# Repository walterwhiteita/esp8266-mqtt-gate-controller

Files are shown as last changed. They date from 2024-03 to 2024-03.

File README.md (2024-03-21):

# MQTT-ESPGate: Retrofit Solution for Gate Control Boards

Welcome to the ESPGate repository! This project offers a comprehensive retrofit solution tailored to upgrade a variety of gate control boards. Leveraging the power of MQTT and ESP8266 modules, this solution provides seamless control over gate automation systems. The repository hosts the design files and documentation for a specialized PCB crafted specifically for this purpose, ensuring easy integration and enhanced functionality for existing gate control setups.

## Project Description

The project aims to upgrade existing automatic gates by adding advanced control and monitoring features. The provided PCB is designed to be integrated into the control boards of installed gates, providing a standardized interface for adding new functionalities without the need to replace the entire system.

## Key Features

- **Remote Commands**: The PCB allows sending remote commands to the gate, enabling opening, closing, and other programmable actions.
- **Status Monitoring**: It's possible to read the current status of the gate, including open, closed signals, and error states.
- **Addition of Clean Contact**: The option to add a clean contact is provided, allowing integration with external control systems or safety devices.

## Repository Structure

- `design/`: Contains PCB design files, including schematics and layouts.
- `docs/`: Additional project documentation.
- `examples/`: Code examples for interfacing with the PCB.
- `LICENSE`: Project license.
- `README.md`: This documentation file.

## Hardware and Software Requirements

### Hardware

- **Opening and Closing Contacts**: The opening and closing contacts present on the gate control board are essential for sending opening and closing commands through our PCB.
- **Indicator Light (optional)**: If available, the indicator light provides visual feedback on the gate's status. In cases where the indicator light is not available, the clean contact already present on our PCB can be used to connect a sensor that detects the gate's open or closed status.

### Software

- **WiFi Connection**: A WiFi connection is required to facilitate communication between the PCB and the MQTT broker, as well as for any configuration operations via mobile devices or computers.
- **MQTT Broker**: An MQTT broker must be available and running, acting as an intermediary for communication between the PCB and other devices or services.

These hardware and software requirements are essential to ensure the proper and reliable operation of the gate control system through the PCB.

## Contributions

Contributions to this project are welcome. Please follow the contribution guidelines described in the `CONTRIBUTING.md` file.

## License

This project is licensed under the [GNU General Public License v3.0](LICENSE). Please refer to the license file for further information.

## Contact

For questions, bug reports, or other inquiries, please contact [Repository Owner's Name](mailto:dimieri00@gmail.com).

---
© 2024 [Repository Owner's Name](https://github.com/walterwhiteita)

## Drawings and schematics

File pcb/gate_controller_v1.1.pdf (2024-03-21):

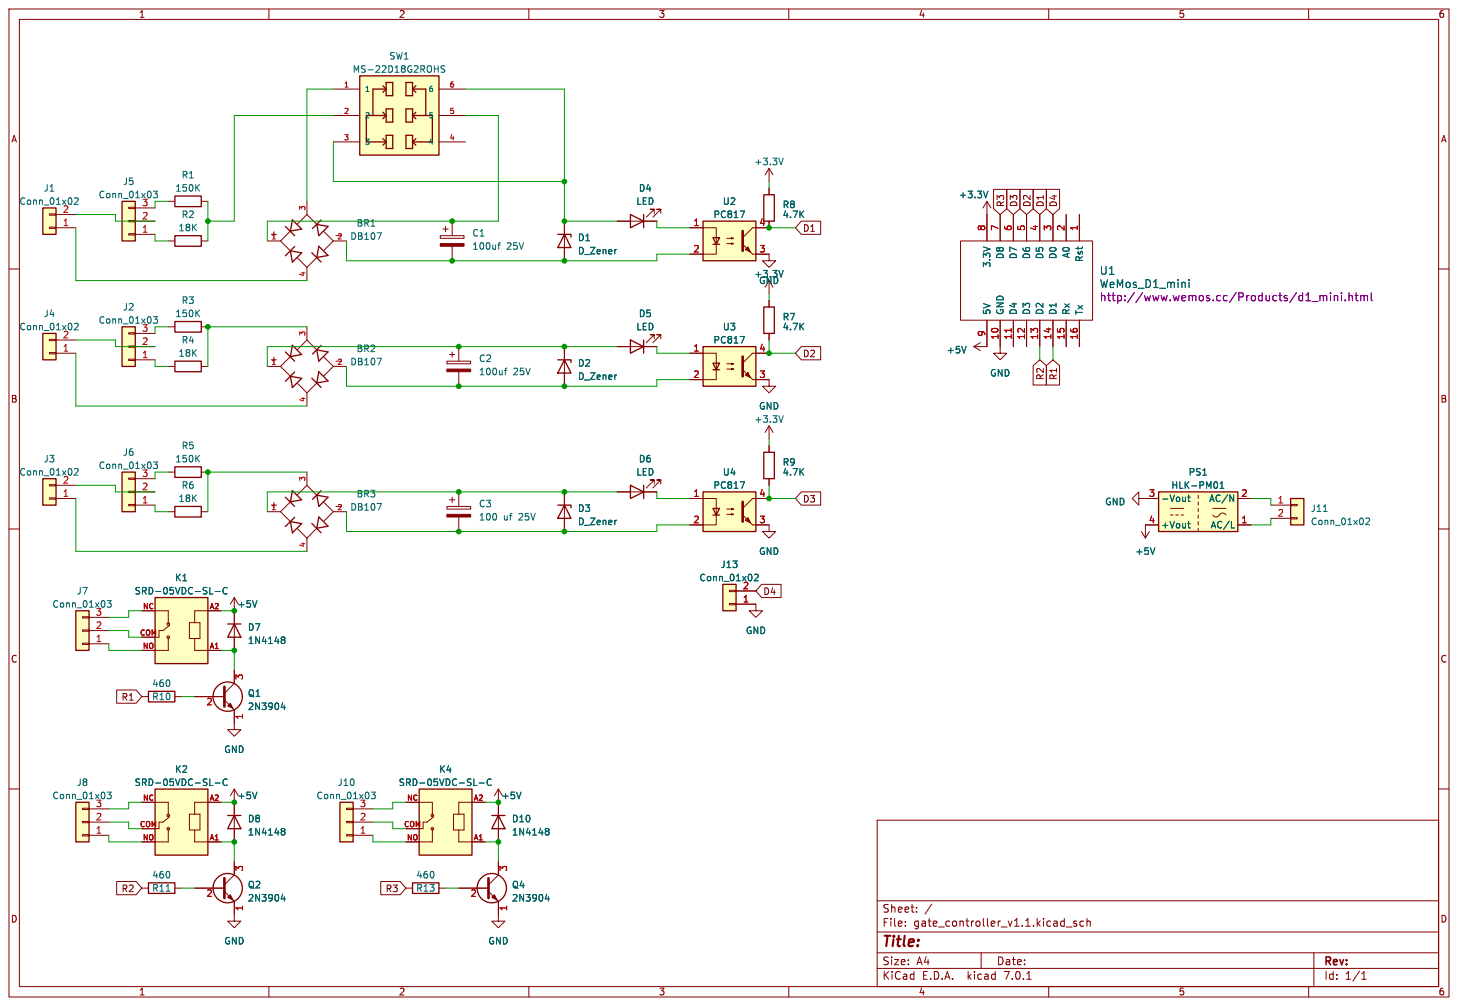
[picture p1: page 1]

http://www.wemos.cc/Products/d1_mini.html D6

Id: 1/1 Title: File: gate_controller_v1.1.kicad_sch Sheet: /

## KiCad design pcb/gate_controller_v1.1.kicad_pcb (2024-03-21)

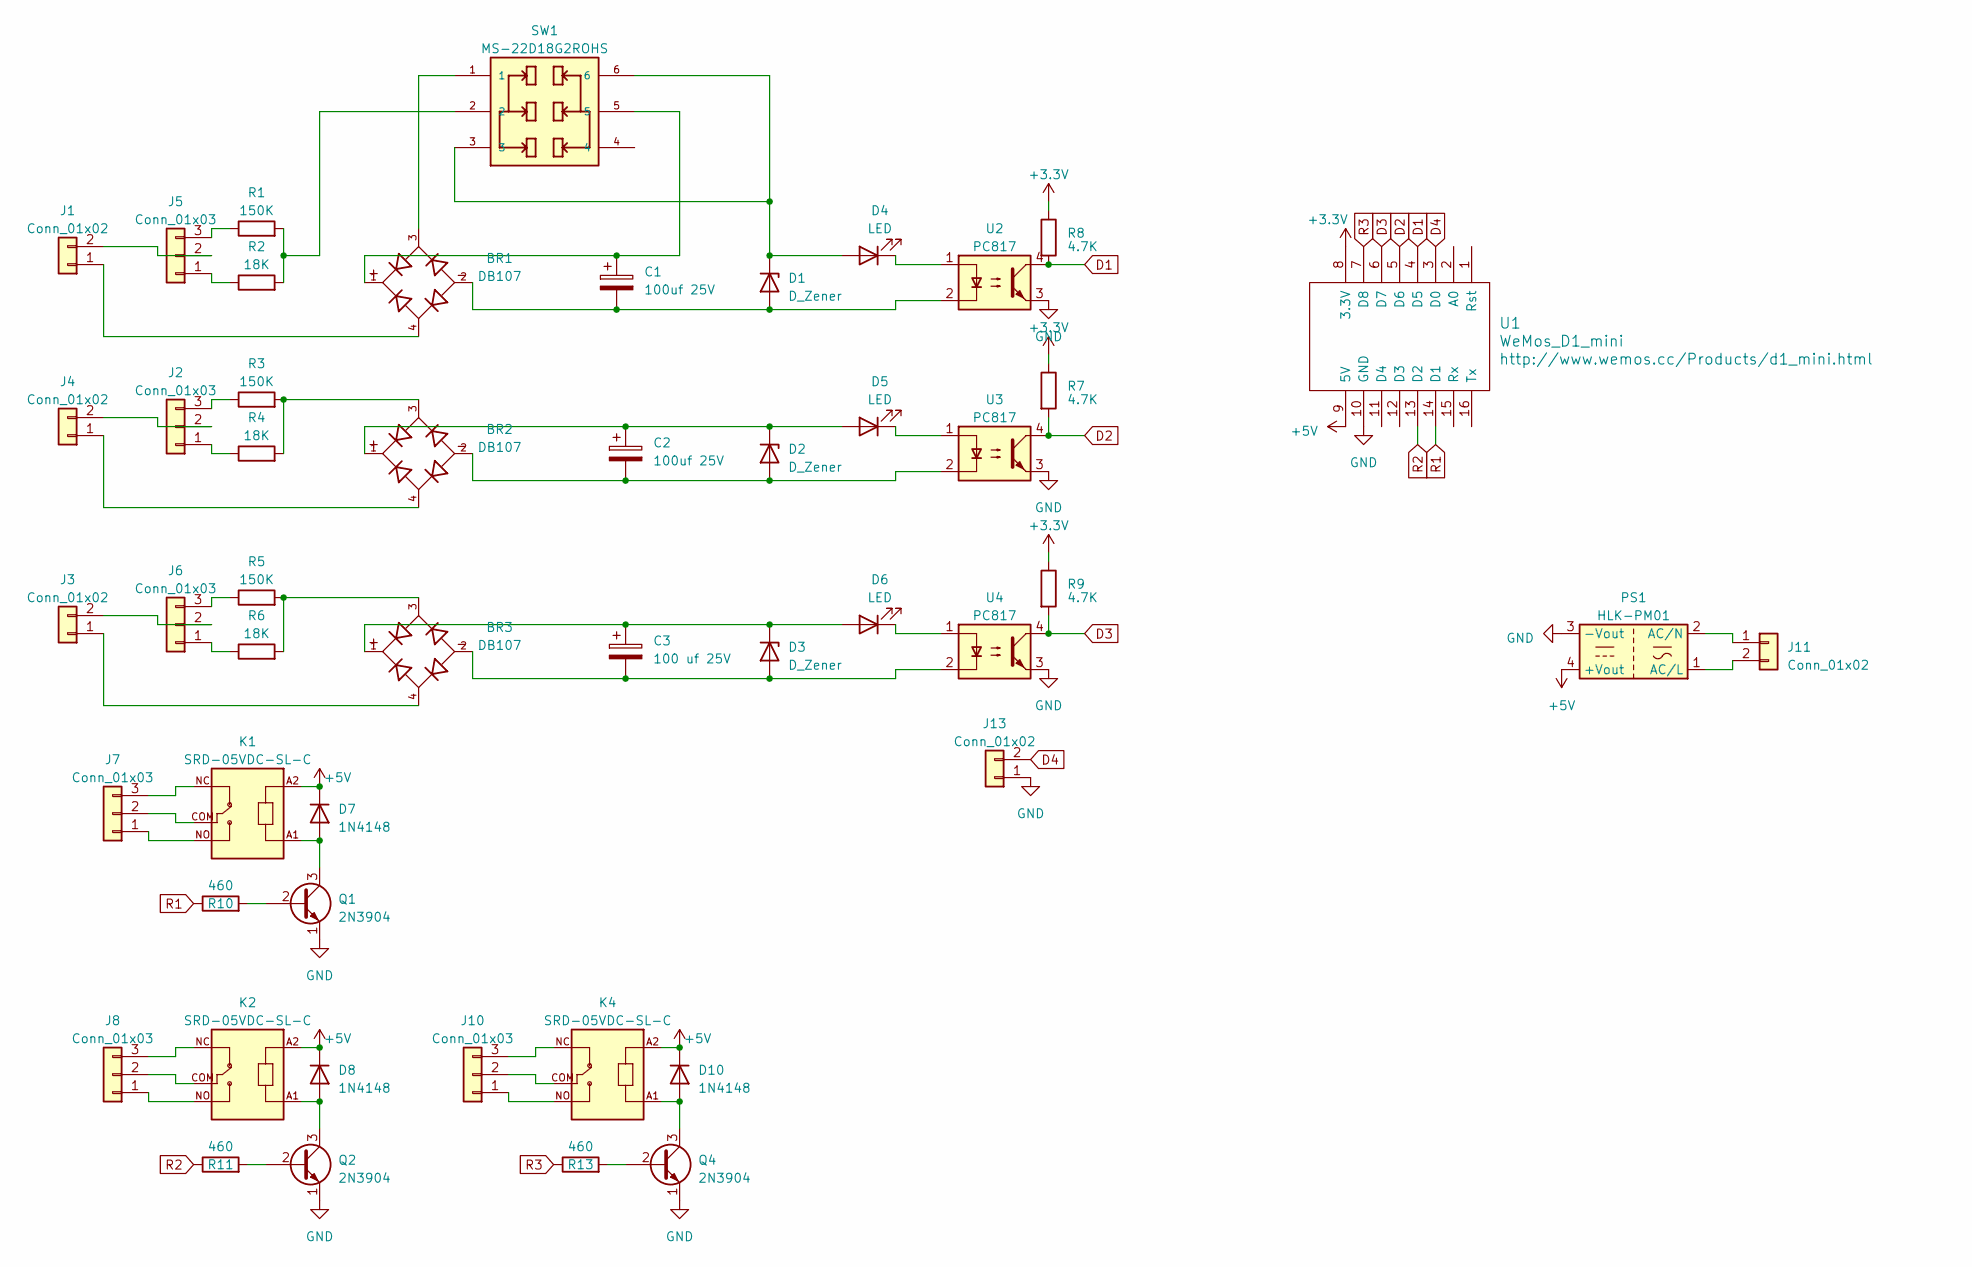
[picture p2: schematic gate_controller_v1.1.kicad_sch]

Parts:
BR1, BR2, BR3: DB107; DIP825W50P509L880H320Q4; PARTREV 13
C1, C2: 100uf 25V; CP_Radial_D6.3mm_P2.50mm
C3: 100 uf 25V; CP_Radial_D6.3mm_P2.50mm
D1, D2, D3: D_Zener; D_DO-41_SOD81_P2.54mm_Vertical_AnodeUp
D4, D5, D6: LED; LED_D5.0mm
D7, D8, D10: 1N4148; D_DO-35_SOD27_P7.62mm_Horizontal
J1, J3, J4, J11: Conn_01x02; TerminalBlock_bornier-2_P5.08mm
J2, J5, J6: Conn_01x03; PinHeader_1x03_P2.54mm_Vertical
J7, J8, J10: Conn_01x03; TerminalBlock_bornier-3_P5.08mm
J13: Conn_01x02; PhoenixContact_MCV_1,5_2-G-3.81_1x02_P3.81mm_Vertical
K1, K2, K4: SRD-05VDC-SL-C; RELAY_SRD-05VDC-SL-C
PS1: HLK-PM01; Converter_ACDC_HiLink_HLK-PMxx
Q1, Q2, Q4: 2N3904; TO-92_Inline
R1, R3, R5: 150K; R_Axial_DIN0414_L11.9mm_D4.5mm_P20.32mm_Horizontal
R2, R4, R6: 18K; R_Axial_DIN0414_L11.9mm_D4.5mm_P20.32mm_Horizontal
R7, R8, R9: 4.7K; R_Axial_DIN0207_L6.3mm_D2.5mm_P2.54mm_Vertical
R10, R11, R13: 460; R_Axial_DIN0207_L6.3mm_D2.5mm_P2.54mm_Vertical
SW1: MS-22D18G2ROHS; SW_MS-22D18G2ROHS
U1: WeMos_D1_mini; wemos-d1-mini-connectors-only
U2, U3, U4: PC817; DIP-4_W7.62mm

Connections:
+3.3V: R7.1, R8.1, R9.1, U1.8 (3.3V)
+5V: D7.1 (K), D8.1 (K), D10.1 (K), K1.A2, K2.A2, K4.A2, PS1.4 (+Vout), U1.9 (5V)
D1: R8.2, U1.4 (D5), U2.4
D2: R7.2, U1.5 (D6), U3.4
D3: R9.2, U1.6 (D7), U4.4
D4: J13.2, U1.3 (D0)
GND: J13.1, PS1.3 (-Vout), Q1.1 (E), Q2.1 (E), Q4.1 (E), U1.10 (GND), U2.3, U3.3, U4.3
unnamed: BR1.1, C1.1, SW1.5
unnamed: BR1.3, SW1.1
unnamed: BR2.3, R3.2, R4.2
unnamed: BR3.3, R5.2, R6.2
unnamed: BR1.2, C1.2, D1.2 (A), U2.2
unnamed: D1.1 (K), D4.2 (A), SW1.3, SW1.6
unnamed: BR2.2, C2.2, D2.2 (A), U3.2
unnamed: BR2.1, C2.1, D2.1 (K), D5.2 (A)
unnamed: BR3.2, C3.2, D3.2 (A), U4.2
unnamed: BR3.1, C3.1, D3.1 (K), D6.2 (A)
unnamed: D4.1 (K), U2.1
unnamed: D5.1 (K), U3.1
unnamed: D6.1 (K), U4.1
unnamed: D7.2 (A), K1.A1, Q1.3 (C)
unnamed: D8.2 (A), K2.A1, Q2.3 (C)
unnamed: D10.2 (A), K4.A1, Q4.3 (C)
unnamed: BR1.4, J1.1
unnamed: J1.2, J5.2
unnamed: J2.1, R4.1
unnamed: J2.2, J4.2
unnamed: J2.3, R3.1
unnamed: BR3.4, J3.1
unnamed: J3.2, J6.2
unnamed: BR2.4, J4.1
unnamed: J5.1, R2.1
unnamed: J5.3, R1.1
unnamed: J6.1, R6.1
unnamed: J6.3, R5.1
unnamed: J7.1, K1.NO
unnamed: J7.2, K1.COM
unnamed: J7.3, K1.NC
unnamed: J8.1, K2.NO
unnamed: J8.2, K2.COM
unnamed: J8.3, K2.NC
unnamed: J10.1, K4.NO
unnamed: J10.2, K4.COM
unnamed: J10.3, K4.NC
unnamed: J11.1, PS1.2 (AC/N)
unnamed: J11.2, PS1.1 (AC/L)
unnamed: Q1.2 (B), R10.2
unnamed: Q2.2 (B), R11.2
unnamed: Q4.2 (B), R13.2
unnamed: R1.2, R2.2, SW1.2
R1: R10.1, U1.14 (D1)
R2: R11.1, U1.13 (D2)
R3: R13.1, U1.7 (D8)

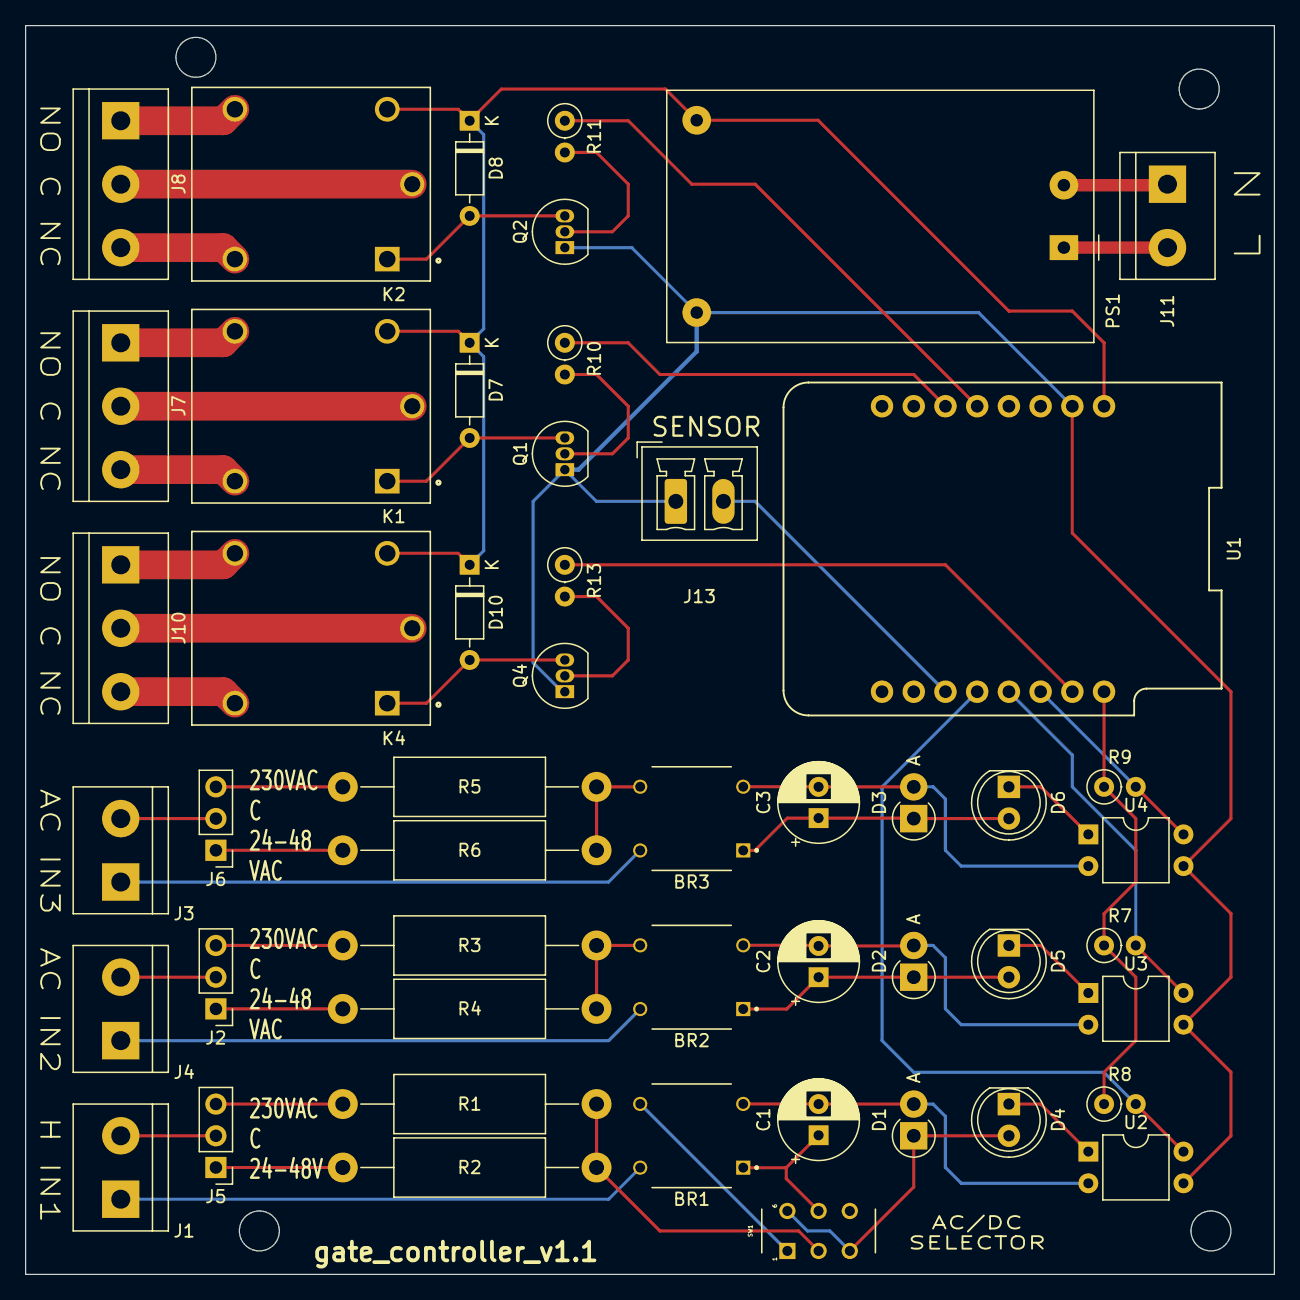
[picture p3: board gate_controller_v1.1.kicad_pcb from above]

Board: 2 copper layers, 100.0 x 100.0 mm, 50 parts (0 on the bottom side), 53 nets.

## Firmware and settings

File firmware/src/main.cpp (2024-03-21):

#include <Arduino.h>
#include <ESP8266WiFi.h>
#include <ESPAsyncTCP.h>
#include <ESPAsyncWebServer.h>
#include <PubSubClient.h>

#include "fs_functions.h"
#include "html_pages.h"
#include "wifi_functions.h"
#include "settings.h"
#include "core_functions.h"
#include "server_functions.h"
#include "mqtt_functions.h"
#include "shared.h"

wifi_conf_t wifi_conf;
mqtt_conf_t mqtt_conf;
module_conf_t module_conf;

AsyncWebServer server(80);

bool shouldReboot = false;
bool hasWifiConfig = false;
bool hasMqttConfig = false;

int mqttCounter=0;
String clientId = DEFAULT_CLIENTID_PREFIX;


void setup() {
  WiFi.scanNetworks();
  setupPin();
  Serial.begin(115200);
  clientId += String(ESP.getChipId(), DEC);
  initializeServerEndpoints();
  if(loadFS()==0){
    hasWifiConfig = (loadWifiConfiguration(&wifi_conf)==0);
    if(!hasWifiConfig){
      wifi_ap_start();
    }
    else{
      if(wifi_sta_start() == 0){
        if(loadMqttConfiguration(&mqtt_conf)==0){
          hasMqttConfig = true;
          mqttSetupClient();
        }
      }
    }
  }
  setupOta();
}

void loop() {
  shouldRebootCheck();
  if(wifi_connection_loop_handler()==0&&hasMqttConfig&&!mqttConnected()&&mqttCounter!=-1){
    mqttReconnect();
  }
  mqttReconnectTimerHandler();
  mqttForceLog();
  mqttLoop();
  stateUpdate();
  loopOta();
}

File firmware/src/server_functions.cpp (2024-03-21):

#include <Arduino.h>
#include <ESP8266WiFi.h>
#include <ESPAsyncTCP.h>
#include <ESPAsyncWebServer.h>
#include <ElegantOTA.h>

#include "mqtt_functions.h"
#include "html_pages.h"
#include "fs_functions.h"
#include "shared.h"
#include "settings.h"

extern AsyncWebServer server;
extern wifi_conf_t wifi_conf;
extern mqtt_conf_t mqtt_conf;
extern bool shouldReboot;
extern bool hasWifiConfig;
extern bool hasMqttConfig;
extern String clientId;

String wifiprocessor(const String& var);
String mqttprocessor(const String& var);
String indexprocessor(const String& var);
bool checkWifiParams();
bool checkMqttParams(AsyncWebServerRequest *request);

unsigned long ota_progress_millis = 0;

void initializeServerEndpoints(){
  //Setup response for wifi
    server.on("/wifi", HTTP_ANY, [](AsyncWebServerRequest *request){
      if(request->method() == HTTP_GET){
        request->send_P(200, "text/html",wifiConfigPage,wifiprocessor);
      }
      else if(request->method() == HTTP_POST){
        if(request->params()>0){
          strcpy(wifi_conf.ssid,request->arg("ssid").c_str());
          strcpy(wifi_conf.pw,request->arg("password").c_str());
          strcpy(wifi_conf.client_name,request->arg("hostname").c_str());
          if(storeWifiConfiguration(&wifi_conf)==0){
            request->send(200, "text/html",rebootPage);
            shouldReboot = true;
          }
          else{
            request->send(200, "text/html",errorPage);// sostituire con error page
          }
        }
        else{
            request->send(200, "text/html",errorPage);// sostituire con error page
        }
      }
    });
    //Setup response richiesta stile
    server.on("/style.css", HTTP_GET, [](AsyncWebServerRequest *request)
              { request->send_P(200, "text/css", style); });
    //Setup response for scan wifi
    server.on("/scan", HTTP_GET, [](AsyncWebServerRequest *request)
    {
    String json = "[";
    int n = WiFi.scanComplete();
    if(n == -2){
      WiFi.scanNetworks(true);
    } else if(n){
      for (int i = 0; i < n; ++i){
        if(i) json += ",";
        json += "{";
        json += "\"rssi\":"+String(WiFi.RSSI(i));
        json += ",\"ssid\":\""+WiFi.SSID(i)+"\"";
        json += ",\"bssid\":\""+WiFi.BSSIDstr(i)+"\"";
        json += ",\"channel\":"+String(WiFi.channel(i));
        json += ",\"secure\":"+String(WiFi.encryptionType(i));
        json += ",\"hidden\":"+String(WiFi.isHidden(i)?"true":"false");
        json += "}";
      }
      WiFi.scanDelete();
      if(WiFi.scanComplete() == -2){
        WiFi.scanNetworks(true);
      }
    }
    json += "]";
    request->send(200, "application/json", json);
    json = String(); });
  //Setup response for mqtt
    server.on("/mqtt", HTTP_ANY, [](AsyncWebServerRequest *request){
      if(request->method() == HTTP_GET){
       request->send_P(200, "text/html",mqttConfigPage,mqttprocessor);
      }
      else if(request->method() == HTTP_POST){
        if(request->params()== 7 && checkMqttParams(request)){
          strcpy(mqtt_conf.ip,request->getParam("broker",true)->value().c_str());
          mqtt_conf.port = atoi(request->getParam("port",true)->value().c_str());
          strcpy(mqtt_conf.availability_topic,request->getParam("username",true)->value().c_str());
          strcpy(mqtt_conf.password,request->getParam("password",true)->value().c_str());
          strcpy(mqtt_conf.availability_topic,request->getParam("availability-topic",true)->value().c_str());
          strcpy(mqtt_conf.command_topic,request->getParam("command-topic",true)->value().c_str());
          strcpy(mqtt_conf.state_topic,request->getParam("state-topic",true)->value().c_str());
          if(storeMqttConfiguration(&mqtt_conf)==0){
            request->send_P(200, "text/html",rebootPage);
            shouldReboot = true;
          }
          else{
            Serial.println("Errore salvataggio");
            request->send_P(200, "text/html",errorPage);
          }
        }
        else{
          Serial.println("Errore lettura parametri");
          Serial.println(request->args());
          request->send_P(200, "text/html",errorPage);
        }
      }
    });
    //Riavvio forzato
    server.on("/reboot", HTTP_POST, [](AsyncWebServerRequest *request){
      request->send_P(200, "text/html",rebootPage);
      shouldReboot = true;
    });
    //Reset
    server.on("/reset", HTTP_POST, [](AsyncWebServerRequest *request){
        if(request->params()==1 && request->hasParam("checked",true)){
              request->send_P(200, "text/html",rebootPage);
        }
        else{
            request->send_P(200, "text/html",errorPage);
        }
    });
    //Index
    server.on("/",HTTP_GET,[](AsyncWebServerRequest *request){
      request->send_P(200, "text/html",indexPage,indexprocessor);
    });
    server.begin();
    Serial.println("HTTP server started");
}
String indexprocessor(const String& var){
  if(var == "MQTT_STATUS"){
    if(hasMqttConfig){
      if(mqttConnected())
        return "CONNECTED";
      else
        return "DISCONNETTED";
    }
    else
      return "NOT CONFIGURED";
  }
  return String();
}
String wifiprocessor(const String& var) {
    if(var=="SAVED_HOSTNAME"){
      if(hasWifiConfig)
        return wifi_conf.client_name;
      else
        return clientId;
    }
    else if(var=="SAVED_SSID"){
      if(hasWifiConfig)
        return wifi_conf.ssid;
    }
    else if(var=="SAVED_PASSWORD"){
      if(hasWifiConfig)
        return wifi_conf.pw;
    }
    return String();
}

String mqttprocessor(const String& var){
  if(var=="BROKER"){
    if(hasMqttConfig)
      return mqtt_conf.ip;
    else
      return String();
  }
  else if(var=="PORT")
  {
    if(hasMqttConfig)
      return String(mqtt_conf.port);
    else
      return String("1883");
  }
  else if(var=="USERNAME")
  {
    if(hasMqttConfig)
      return mqtt_conf.username;
    else
      return String();
  }
  else if(var=="PASSWORD")
  {
    if(hasMqttConfig)
      return mqtt_conf.password;
    else
      return String();
  }
  else if(var=="AVAILABILITY_TOPIC")
  {
    if(hasMqttConfig)
      return mqtt_conf.availability_topic;
    else
      return clientId+String(AVAILABILITY_TOPIC);
  }
  else if(var=="COMMAND_TOPIC")
  {
    if(hasMqttConfig)
      return mqtt_conf.command_topic;
    else
      return clientId+String(COMMAND_TOPIC);
  }
  else if(var=="STATE_TOPIC")
  {
    if(hasMqttConfig)
      return mqtt_conf.state_topic;
    else
      return clientId+String(STATE_TOPIC);
  }
  return String();
}

void onOTAStart() {
  // Log when OTA has started
  Serial.println("OTA update started!");
  // <Add your own code here>
}

void onOTAProgress(size_t current, size_t final) {
  // Log every 1 second
  if (millis() - ota_progress_millis > 1000) {
    ota_progress_millis = millis();
    Serial.printf("OTA Progress Current: %u bytes, Final: %u bytes\n", current, final);
  }
}
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

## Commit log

2024-02-26 Add files via upload
    KiCad PCB
    [came_wifi_v2.kicad_pcb, came_wifi_v2.kicad_sch]
2024-03-19 Changed pin
2024-03-21 pcb_v1.1
    fixed gpio
    added:
    - ac/dc mode selector
    - sensor contact
    [gate_controller_v1.1.kicad_pcb, gate_controller_v1.1.kicad_sch]
